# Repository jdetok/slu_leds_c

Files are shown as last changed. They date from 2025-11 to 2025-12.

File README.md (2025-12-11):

# SLU Fleur de Lis Lights Display
designed by Justin DeKock - Fall 2025
#
`
# [SEE USER GUIDE/INSTRUCTIONS HERE](USERGUIDE.md)
- ## [Demo Video](https://youtu.be/l19p7q0IOvI)
# [SEE BILL OF MATERIALS (ELECTRONICS PARTS) HERE](BOM.md)

## Firmware
- the device's [firmware](firmware/) is written in C++ 
- built and uploaded to Arduino with [PlatformIO](https://platformio.org/) [VSCode extension](https://platformio.org/install/ide?install=vscode)

## Printed Circuit Board (PCB)
- the [electrical schematic and the PCB](pcb/) were designed in [KiCad](https://www.kicad.org/)

## repo organization
- ### pcb/ 
    - contains KiCAD project with shematic/PCB files 
- ### firmware/
    - contains C++ firmware that gets uploaded to the arduino
    - project

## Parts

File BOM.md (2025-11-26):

# bill of materials for SLU LEDs display

- ### arduino
    - Arduino Nano V3 (USB-C)
- ### Bulk capacitor
    - aluminum electrolytic SMD
    - 4mm x 5.4mm
    - 10uf
    - JLC
        - C3343
        - https://jlcpcb.com/partdetail/HonorElec-RVT1E100M0405/C3343
- ### ICs
    - all SOP16 package
    - #### SIPO
        - 74HC595
        - JLC
            - C79097
            - https://jlcpcb.com/partdetail/80234-TM74HC595/C79097
    - #### PISO
        - 74HC165
        - JLC
            - C61060
            - https://jlcpcb.com/partdetail/TexasInstruments-SN74HC165DR/C61060
- ### Decoupling caps
    - 1206 package
    - 100nf
    - JLC
        - C24497
        - https://jlcpcb.com/partdetail/25237-CL31B104KBCNNNC/C24497
- ### LED x64
    - 3528 package
    - JLC
        - WHITE
            - C50327302
            - https://jlcpcb.com/partdetail/52924801-67_21S_KK5C_H602633Z62T/C50327302
        - BLUE
            - C51933338
            - https://jlcpcb.com/partdetail/Gui_guanglight-GL3528UB01/C51933338
    
- ### Resistors for LEDs x64
    - 470 ohm | 1206 pacage
    - JLC
        - C4502 (extended, try to find basic)
        - https://jlcpcb.com/partdetail/4909-1206W4F4700T5E/C4502
- ### Buttons x8
    - 4x3mm
    - JLC
        - C720477
        - https://jlcpcb.com/partdetail/XUNPU-TS_1088AR02016/C720477
- ### Resistors for buttons x8
    - 10k ohm | 1206 pacage
    - JLC
        - C17902
        - https://jlcpcb.com/partdetail/18590-1206W4F1002T5E/C17902
- ### Battery
    - single cell 18650 li-ion
- ### Battery charging module
    - from amazon
    - https://a.co/d/5A0npPp
    - RIGHT ANGLE HEADERS TO ATTACH TO BOARD
        - https://a.co/d/j1yIO91
- ### Schottky diode
    - SS34
    - SMA package
    - JLC
        - C8678
        - https://jlcpcb.com/partdetail/MDD_Microdiode_Semiconductor-SS34/C8678
- ### 5-pin out for external LCD
    - 5 pins, 2.54mm pitch
- ### Pins for battery
    - 2 pins, right angle bend
    - 2.54mm pitch

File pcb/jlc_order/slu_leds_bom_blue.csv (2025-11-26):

Reference | Qty | Value | DNP | Exclude from BOM | Exclude from Board | Footprint | Datasheet | LCSC Part #
bc1 | 1 | bc10µf_5054 |  |  |  | slu_leds_lib:CP_Elec_4x5.4 | https://jlcpcb.com/api/file/downloadByFileSystemAccessId/8588886801545375744 | C3343
r1,r2,r3,r4,r5,r6,r7,r8,r9,r10,r11,r12,r13,r14,r15,r16,r17,r18,r19,r20,r21,r22,r23,r24,r25,r26,r27,r28,r29,r30,r31,r32,r33,r34,r35,r36,r37,r38,r39,r40,r41,r42,r43,r44,r45,r46,r47,r48,r49,r50,r51,r52,r53,r54,r55,r56,r57,r58,r59,r60,r61,r62,r63,r64 | 64 | 470Ω |  |  |  | slu_leds_lib:r_470Ω_1206 | https://jlcpcb.com/api/file/downloadByFileSystemAccessId/8586177295745241088 | C4502
DIO1 | 1 | SS34 |  |  |  | slu_leds_lib:D_SMA | https://www.vishay.com/docs/88751/ss32.pdf | C8678
r65,r66,r67,r68,r69,r70,r71,r72 | 8 | 10KΩ |  |  |  | slu_leds_lib:r_10KΩ_1206 | https://jlcpcb.com/api/file/downloadByFileSystemAccessId/8579705876598476800 | C17902
c1,c2,c3,c4,c5,c6,c7,c8,c9 | 9 | 100nf |  |  |  | a_detolib:cap1206 | https://jlcpcb.com/api/file/downloadByFileSystemAccessId/8579707339533963264 | C24497
ICI1 | 1 | 74HC165 |  |  |  | slu_leds_lib:sop16_hc165 | https://jlcpcb.com/api/file/downloadByFileSystemAccessId/8603367375115079680 | C61060
ICO1,ICO2,ICO3,ICO4,ICO5,ICO6,ICO7,ICO8 | 8 | 74HC595 |  |  |  | slu_leds_lib:sop16_hc595 | https://jlcpcb.com/api/file/downloadByFileSystemAccessId/8586176303707377664 | C79097
b1,b2,b3,b4,b5,b6,b7,b8 | 8 | btn |  |  |  | slu_leds_lib:btn_4x3 | https://jlcpcb.com/api/file/downloadByFileSystemAccessId/8588886944068096000 | C720477
d1,d2,d3,d4,d5,d6,d7,d8,d9,d10,d11,d12,d13,d14,d15,d16,d17,d18,d19,d20,d21,d22,d23,d24,d25,d26,d27,d28,d29,d30,d31,d32,d33,d34,d35,d36,d37,d38,d39,d40,d41,d42,d43,d44,d45,d46,d47,d48,d49,d50,d51,d52,d53,d54,d55,d56,d57,d58,d59,d60,d61,d62,d63,d64 | 64 | LED |  |  |  | slu_leds_lib:blue_led_3528 |  | C51933338

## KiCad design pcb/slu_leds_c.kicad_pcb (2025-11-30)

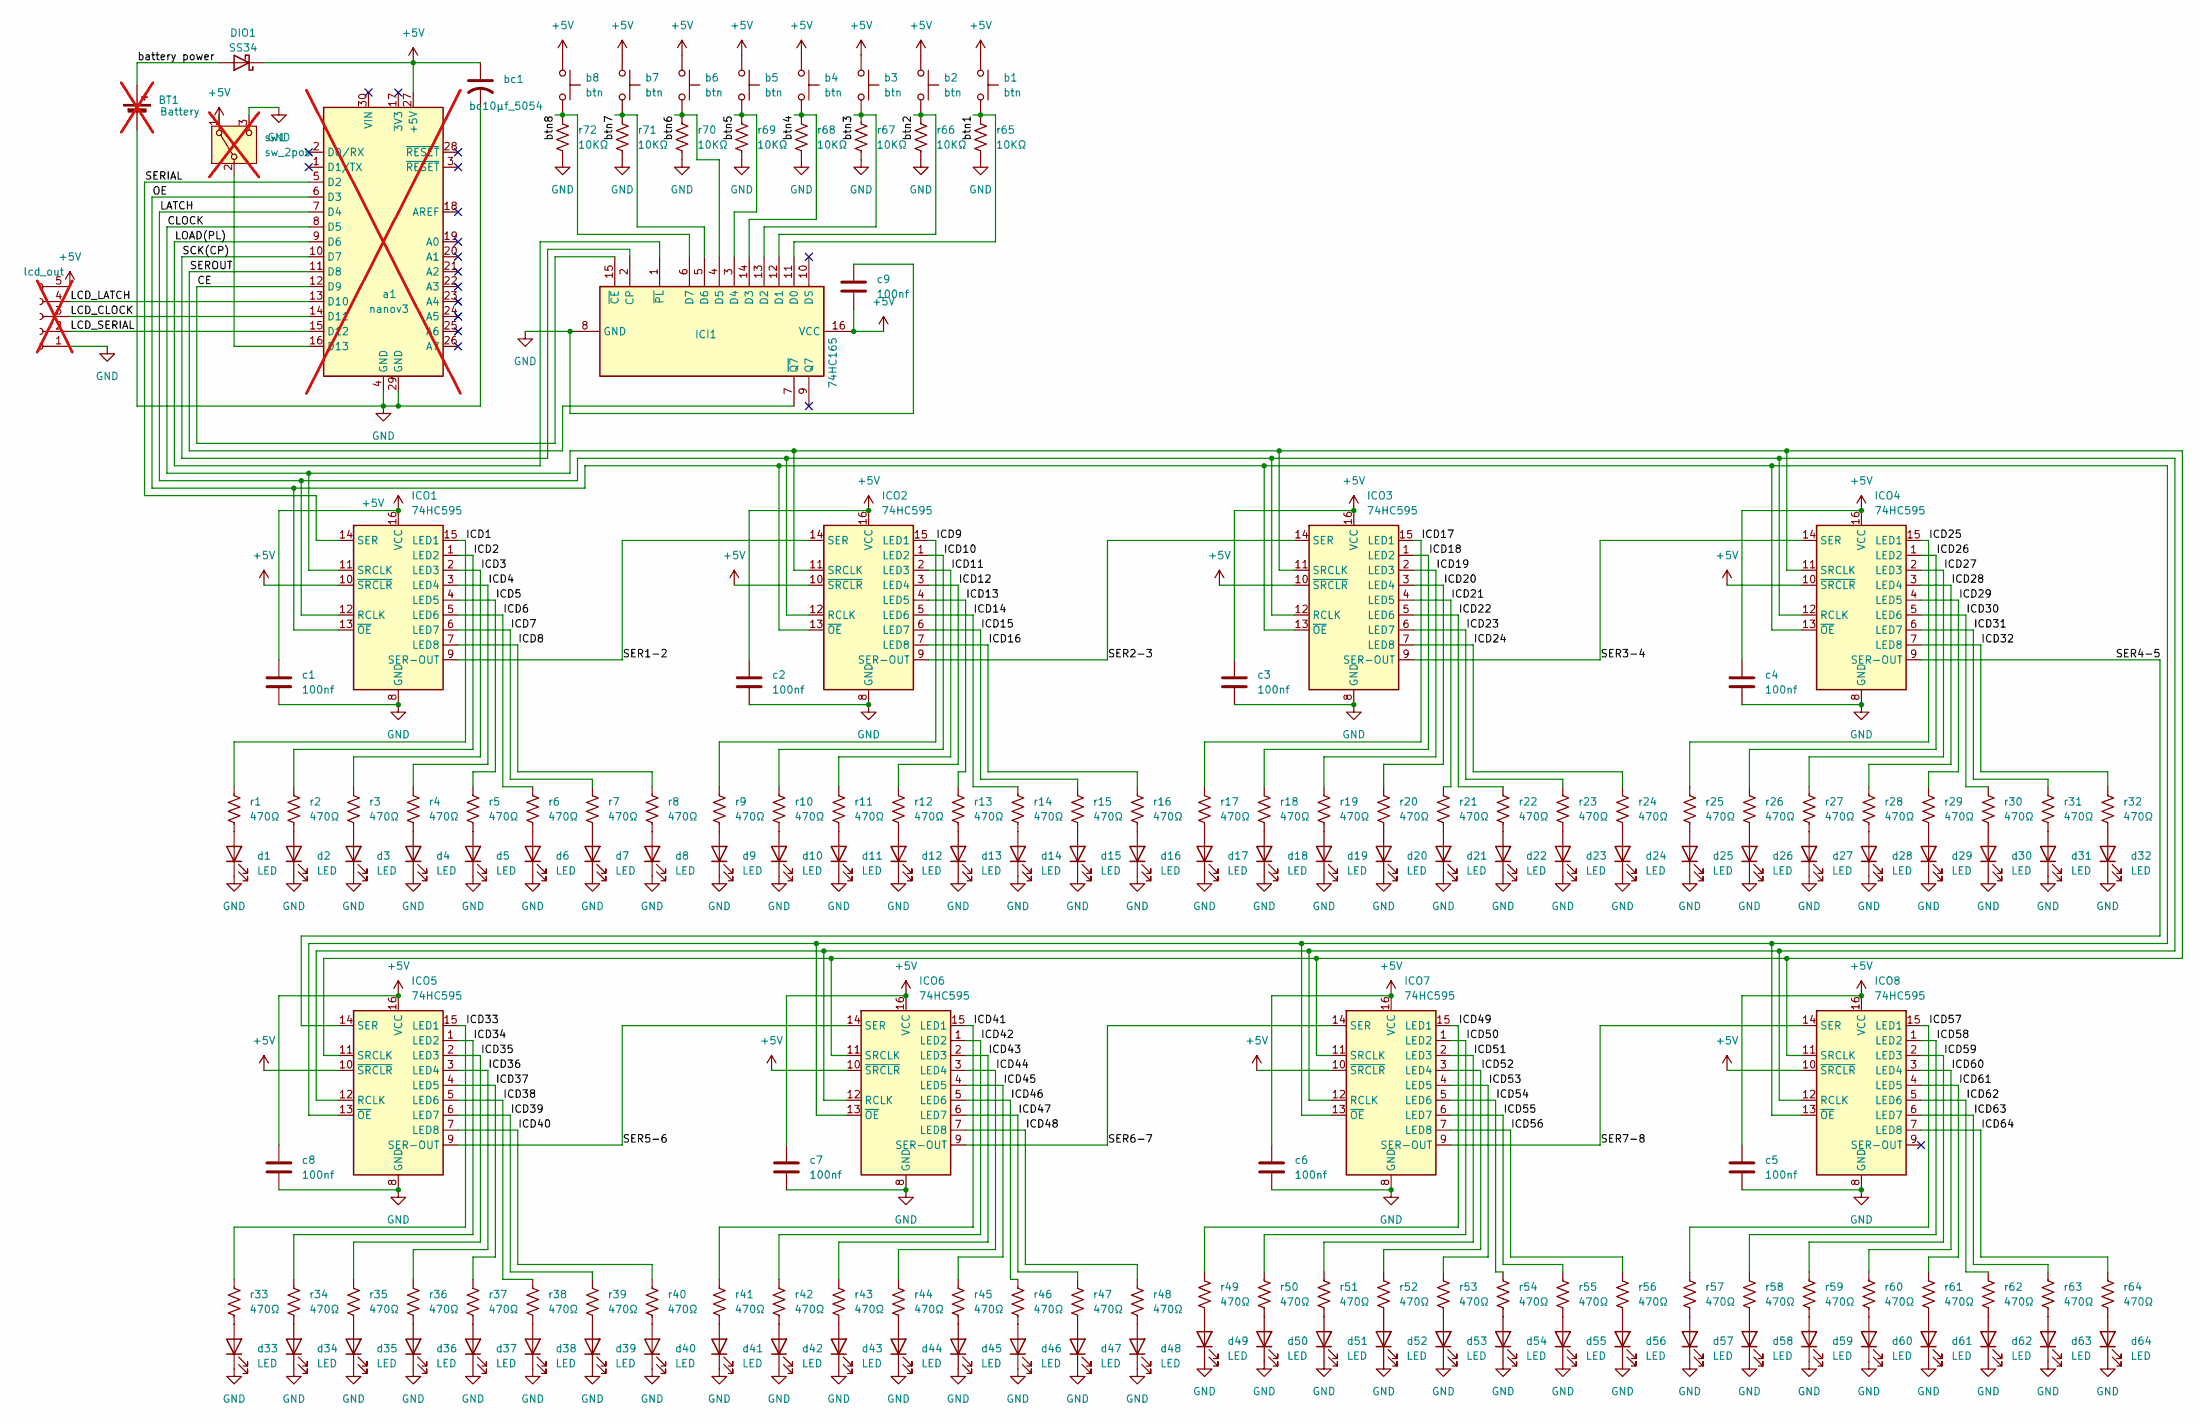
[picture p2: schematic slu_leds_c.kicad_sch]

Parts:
BT1: Battery; btry_18650_foirot; not fitted
DIO1: SS34; D_SMA; LCSC Part # C8678
ICI1: 74HC165; sop16_hc165; LCSC Part # C61060
ICO1, ICO2, ICO3, ICO4, ICO5, ICO6, ICO7, ICO8: 74HC595; sop16_hc595; LCSC Part # C79097
J1: lcd_out; 5pin_2.54; not fitted
a1: nanov3; not fitted
b1, b2, b3, b4, b5, b6, b7, b8: btn; btn_4x3; LCSC Part # C720477
bc1: bc10µf_5054; CP_Elec_4x5.4; LCSC Part # C3343
c1, c2, c3, c4, c5, c6, c7, c8, c9: 100nf; cap1206; LCSC Part # C24497
d1, d2, d3, d4, d5, d6, d7, d8, d9, d10, d11, d12, d13, d14, d15, d16, d17, d18, d19, d20, d21, d22, d23, d24, d25, d26, d27, d28, d29, d30, d31, d32, d33, d34, d35, d36, d37, d38, d39, d40, d41, d42, d43, d44, d45, d46, d47, d48, d49, d50, d51, d52, d53, d54, d55, d56, d57, d58, d59, d60, d61, d62, d63, d64: LED; blue_led_3528; LCSC Part # C50327302
r1, r2, r3, r4, r5, r6, r7, r8, r9, r10, r11, r12, r13, r14, r15, r16, r17, r18, r19, r20, r21, r22, r23, r24, r25, r26, r27, r28, r29, r30, r31, r32, r33, r34, r35, r36, r37, r38, r39, r40, r41, r42, r43, r44, r45, r46, r47, r48, r49, r50, r51, r52, r53, r54, r55, r56, r57, r58, r59, r60, r61, r62, r63, r64: 470Ω; r_470Ω_1206; LCSC Part # C4502
r65, r66, r67, r68, r69, r70, r71, r72: 10KΩ; r_10KΩ_1206; LCSC Part # C17902
sw1: sw_2pos; sw_2pos_spdt; not fitted

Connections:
+5V: DIO1.1 (K), ICI1.16 (VCC), ICO1.10 (~SRCLR), ICO1.16 (VCC), ICO2.10 (~SRCLR), ICO2.16 (VCC), ICO3.10 (~SRCLR), ICO3.16 (VCC), ICO4.10 (~SRCLR), ICO4.16 (VCC), ICO5.10 (~SRCLR), ICO5.16 (VCC), ICO6.10 (~SRCLR), ICO6.16 (VCC), ICO7.10 (~SRCLR), ICO7.16 (VCC), ICO8.10 (~SRCLR), ICO8.16 (VCC), J1.5, a1.27 (+5V), b1.1, b2.1, b3.1, b4.1, b5.1, b6.1, b7.1, b8.1, bc1.1, c1.1, c2.1, c3.1, c4.1, c5.1, c6.1, c7.1, c8.1, c9.2, sw1.1 (A); also elsewhere on the board
/CE: ICI1.15 (~CE), a1.12 (D9)
/CLOCK: ICO1.11 (SRCLK), ICO2.11 (SRCLK), ICO3.11 (SRCLK), ICO4.11 (SRCLK), ICO5.11 (SRCLK), ICO6.11 (SRCLK), ICO7.11 (SRCLK), ICO8.11 (SRCLK), a1.8 (D5)
/ICD1: ICO1.15 (LED1), r1.2
/ICD2: ICO1.1 (LED2), r2.2
/ICD3: ICO1.2 (LED3), r3.2
/ICD4: ICO1.3 (LED4), r4.2
/ICD5: ICO1.4 (LED5), r5.2
/ICD6: ICO1.5 (LED6), r6.2
/ICD7: ICO1.6 (LED7), r7.2
/ICD8: ICO1.7 (LED8), r8.2
/ICD9: ICO2.15 (LED1), r9.2
/ICD10: ICO2.1 (LED2), r10.2
/ICD11: ICO2.2 (LED3), r11.2
/ICD12: ICO2.3 (LED4), r12.2
/ICD13: ICO2.4 (LED5), r13.2
/ICD14: ICO2.5 (LED6), r14.2
/ICD15: ICO2.6 (LED7), r15.2
/ICD16: ICO2.7 (LED8), r16.2
/ICD17: ICO3.15 (LED1), r17.2
/ICD18: ICO3.1 (LED2), r18.2
/ICD19: ICO3.2 (LED3), r19.2
/ICD20: ICO3.3 (LED4), r20.2
/ICD21: ICO3.4 (LED5), r21.2
/ICD22: ICO3.5 (LED6), r22.2
/ICD23: ICO3.6 (LED7), r23.2
/ICD24: ICO3.7 (LED8), r24.2
/ICD25: ICO4.15 (LED1), r25.2
/ICD26: ICO4.1 (LED2), r26.2
/ICD27: ICO4.2 (LED3), r27.2
/ICD28: ICO4.3 (LED4), r28.2
/ICD29: ICO4.4 (LED5), r29.2
/ICD30: ICO4.5 (LED6), r30.2
/ICD31: ICO4.6 (LED7), r31.2
/ICD32: ICO4.7 (LED8), r32.2
/ICD33: ICO5.15 (LED1), r33.2
/ICD34: ICO5.1 (LED2), r34.2
/ICD35: ICO5.2 (LED3), r35.2
/ICD36: ICO5.3 (LED4), r36.2
/ICD37: ICO5.4 (LED5), r37.2
/ICD38: ICO5.5 (LED6), r38.2
/ICD39: ICO5.6 (LED7), r39.2
/ICD40: ICO5.7 (LED8), r40.2
/ICD41: ICO6.15 (LED1), r41.2
/ICD42: ICO6.1 (LED2), r42.2
/ICD43: ICO6.2 (LED3), r43.2
/ICD44: ICO6.3 (LED4), r44.2
/ICD45: ICO6.4 (LED5), r45.2
/ICD46: ICO6.5 (LED6), r46.2
/ICD47: ICO6.6 (LED7), r47.2
/ICD48: ICO6.7 (LED8), r48.2
/ICD49: ICO7.15 (LED1), r49.2
/ICD50: ICO7.1 (LED2), r50.2
/ICD51: ICO7.2 (LED3), r51.2
/ICD52: ICO7.3 (LED4), r52.2
/ICD53: ICO7.4 (LED5), r53.2
/ICD54: ICO7.5 (LED6), r54.2
/ICD55: ICO7.6 (LED7), r55.2
/ICD56: ICO7.7 (LED8), r56.2
/ICD57: ICO8.15 (LED1), r57.2
/ICD58: ICO8.1 (LED2), r58.2
/ICD59: ICO8.2 (LED3), r59.2
/ICD60: ICO8.3 (LED4), r60.2
/ICD61: ICO8.4 (LED5), r61.2
/ICD62: ICO8.5 (LED6), r62.2
/ICD63: ICO8.6 (LED7), r63.2
/ICD64: ICO8.7 (LED8), r64.2
/LATCH: ICO1.12 (RCLK), ICO2.12 (RCLK), ICO3.12 (RCLK), ICO4.12 (RCLK), ICO5.12 (RCLK), ICO6.12 (RCLK), ICO7.12 (RCLK), ICO8.12 (RCLK), a1.7 (D4)
/LCD_CLOCK: J1.3, a1.14 (D11)
/LCD_LATCH: J1.4, a1.13 (D10)
/LCD_SERIAL: J1.2, a1.15 (D12)
/LOAD(PL): ICI1.1 (~PL), a1.9 (D6)
/OE: ICO1.13 (~OE), ICO2.13 (~OE), ICO3.13 (~OE), ICO4.13 (~OE), ICO5.13 (~OE), ICO6.13 (~OE), ICO7.13 (~OE), ICO8.13 (~OE), a1.6 (D3)
/SCK(CP): ICI1.2 (CP), a1.10 (D7)
/SER1-2: ICO1.9 (SER-OUT), ICO2.14 (SER)
/SER2-3: ICO2.9 (SER-OUT), ICO3.14 (SER)
/SER3-4: ICO3.9 (SER-OUT), ICO4.14 (SER)
/SER4-5: ICO4.9 (SER-OUT), ICO5.14 (SER)
/SER5-6: ICO5.9 (SER-OUT), ICO6.14 (SER)
/SER6-7: ICO6.9 (SER-OUT), ICO7.14 (SER)
/SER7-8: ICO7.9 (SER-OUT), ICO8.14 (SER)
/SERIAL: ICO1.14 (SER), a1.5 (D2)
/SEROUT: ICI1.7 (~Q7), a1.11 (D8)
/btn1: ICI1.11 (D0), b1.2, r65.1
/btn2: ICI1.12 (D1), b2.2, r66.1
/btn3: ICI1.13 (D2), b3.2, r67.1
/btn4: ICI1.14 (D3), b4.2, r68.1
/btn5: ICI1.3 (D4), b5.2, r69.1
/btn6: ICI1.4 (D5), b6.2, r70.1
/btn7: ICI1.5 (D6), b7.2, r71.1
/btn8: ICI1.6 (D7), b8.2, r72.1
GND: BT1.2 (-), ICI1.8 (GND), ICO1.8 (GND), ICO2.8 (GND), ICO3.8 (GND), ICO4.8 (GND), ICO5.8 (GND), ICO6.8 (GND), ICO7.8 (GND), ICO8.8 (GND), J1.1, a1.4 (GND), a1.29 (GND), bc1.2, c1.2, c2.2, c3.2, c4.2, c5.2, c6.2, c7.2, c8.2, c9.1, d1.1 (K), d2.1 (K), d3.1 (K), d4.1 (K), d5.1 (K), d6.1 (K), d7.1 (K), d8.1 (K), d9.1 (K), d10.1 (K), d11.1 (K), d12.1 (K), d13.1 (K), d14.1 (K), d15.1 (K), d16.1 (K), d17.1 (K), d18.1 (K), d19.1 (K), d20.1 (K), d21.1 (K), d22.1 (K), d23.1 (K), d24.1 (K), d25.1 (K), d26.1 (K), d27.1 (K), d28.1 (K), d29.1 (K), d30.1 (K), d31.1 (K), d32.1 (K), d33.1 (K), d34.1 (K), d35.1 (K), d36.1 (K), d37.1 (K), d38.1 (K), d39.1 (K), d40.1 (K), d41.1 (K), d42.1 (K), d43.1 (K), d44.1 (K), d45.1 (K), d46.1 (K), d47.1 (K), d48.1 (K), d49.1 (K), d50.1 (K), d51.1 (K), d52.1 (K), d53.1 (K), d54.1 (K), d55.1 (K), d56.1 (K), d57.1 (K), d58.1 (K), d59.1 (K), d60.1 (K), d61.1 (K), d62.1 (K), d63.1 (K), d64.1 (K), r65.2, r66.2, r67.2, r68.2, r69.2, r70.2, r71.2, r72.2, sw1.3 (C); also elsewhere on the board
unnamed: BT1.1 (+), DIO1.2 (A)
unnamed: a1.16 (D13), sw1.2 (B)
unnamed: d1.2 (A), r1.1
unnamed: d2.2 (A), r2.1
unnamed: d3.2 (A), r3.1
unnamed: d4.2 (A), r4.1
unnamed: d5.2 (A), r5.1
unnamed: d6.2 (A), r6.1
unnamed: d7.2 (A), r7.1
unnamed: d8.2 (A), r8.1
unnamed: d9.2 (A), r9.1
unnamed: d10.2 (A), r10.1
unnamed: d11.2 (A), r11.1
unnamed: d12.2 (A), r12.1
unnamed: d13.2 (A), r13.1
unnamed: d14.2 (A), r14.1
unnamed: d15.2 (A), r15.1
unnamed: d16.2 (A), r16.1
unnamed: d17.2 (A), r17.1
unnamed: d18.2 (A), r18.1
unnamed: d19.2 (A), r19.1
unnamed: d20.2 (A), r20.1
unnamed: d21.2 (A), r21.1
unnamed: d22.2 (A), r22.1
unnamed: d23.2 (A), r23.1
unnamed: d24.2 (A), r24.1
unnamed: d25.2 (A), r25.1
unnamed: d26.2 (A), r26.1
unnamed: d27.2 (A), r27.1
unnamed: d28.2 (A), r28.1
unnamed: d29.2 (A), r29.1
unnamed: d30.2 (A), r30.1
unnamed: d31.2 (A), r31.1
unnamed: d32.2 (A), r32.1
unnamed: d33.2 (A), r33.1
unnamed: d34.2 (A), r34.1
unnamed: d35.2 (A), r35.1
unnamed: d36.2 (A), r36.1
unnamed: d37.2 (A), r37.1
unnamed: d38.2 (A), r38.1
unnamed: d39.2 (A), r39.1
unnamed: d40.2 (A), r40.1
unnamed: d41.2 (A), r41.1
unnamed: d42.2 (A), r42.1
unnamed: d43.2 (A), r43.1
unnamed: d44.2 (A), r44.1
unnamed: d45.2 (A), r45.1
unnamed: d46.2 (A), r46.1
unnamed: d47.2 (A), r47.1
unnamed: d48.2 (A), r48.1
unnamed: d49.2 (A), r49.1
unnamed: d50.2 (A), r50.1
unnamed: d51.2 (A), r51.1
unnamed: d52.2 (A), r52.1
unnamed: d53.2 (A), r53.1
unnamed: d54.2 (A), r54.1
unnamed: d55.2 (A), r55.1
unnamed: d56.2 (A), r56.1
unnamed: d57.2 (A), r57.1
unnamed: d58.2 (A), r58.1
unnamed: d59.2 (A), r59.1
unnamed: d60.2 (A), r60.1
unnamed: d61.2 (A), r61.1
unnamed: d62.2 (A), r62.1
unnamed: d63.2 (A), r63.1
unnamed: d64.2 (A), r64.1

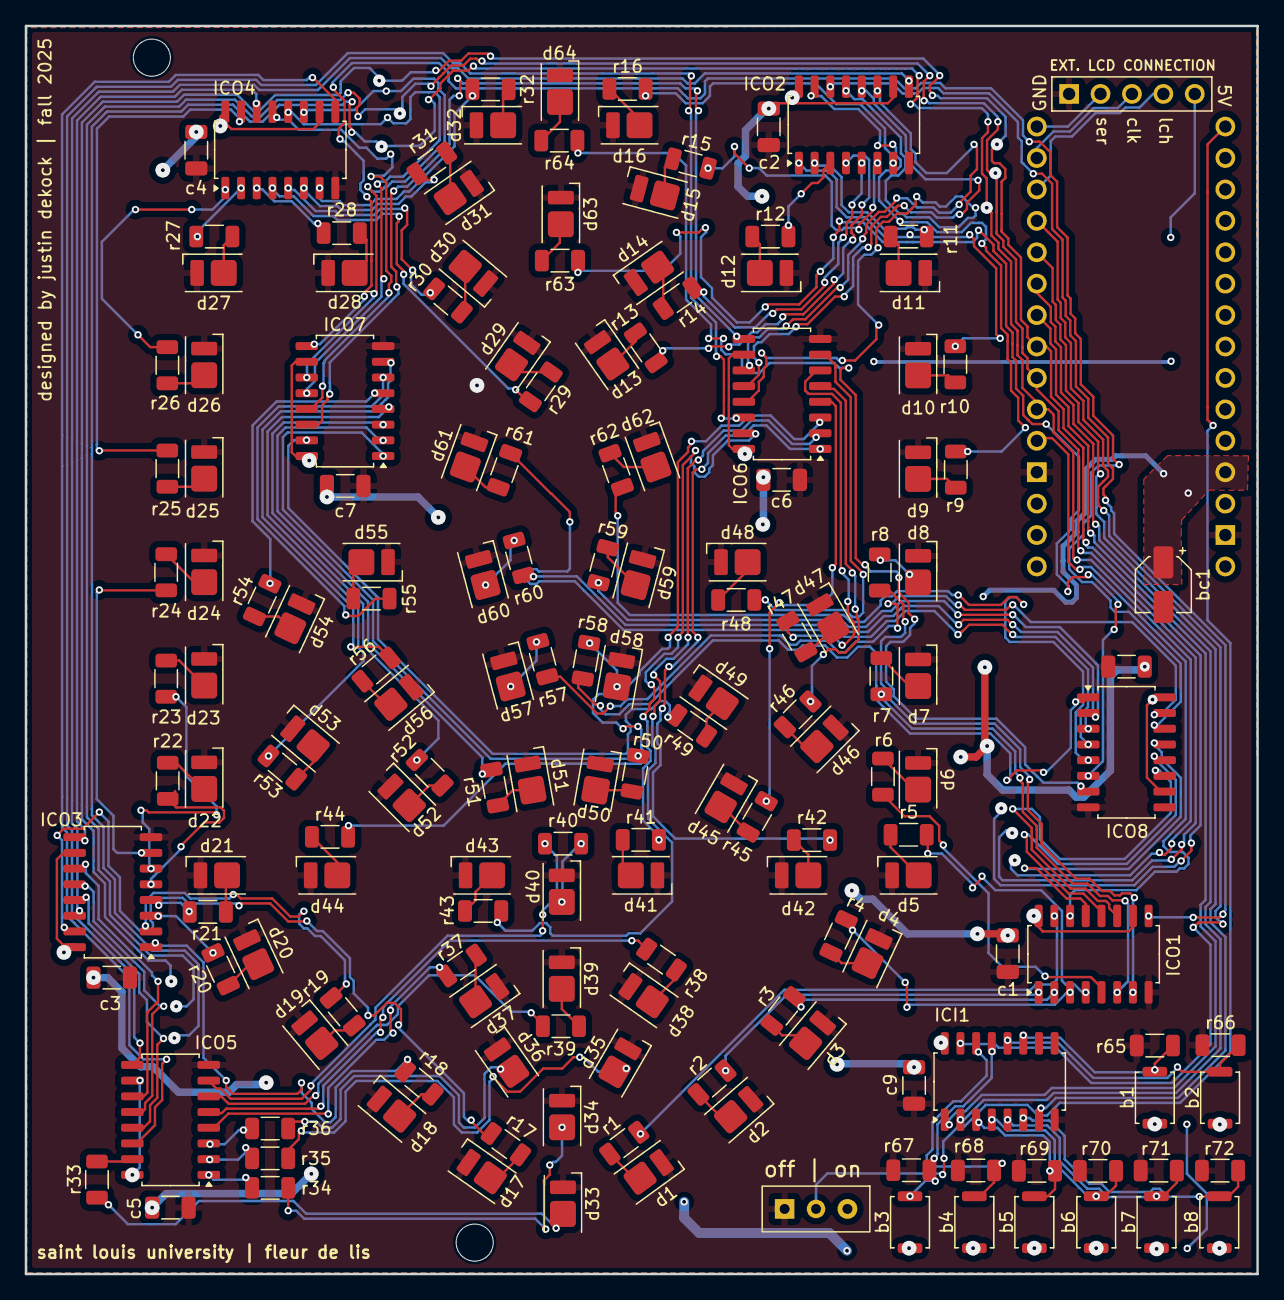
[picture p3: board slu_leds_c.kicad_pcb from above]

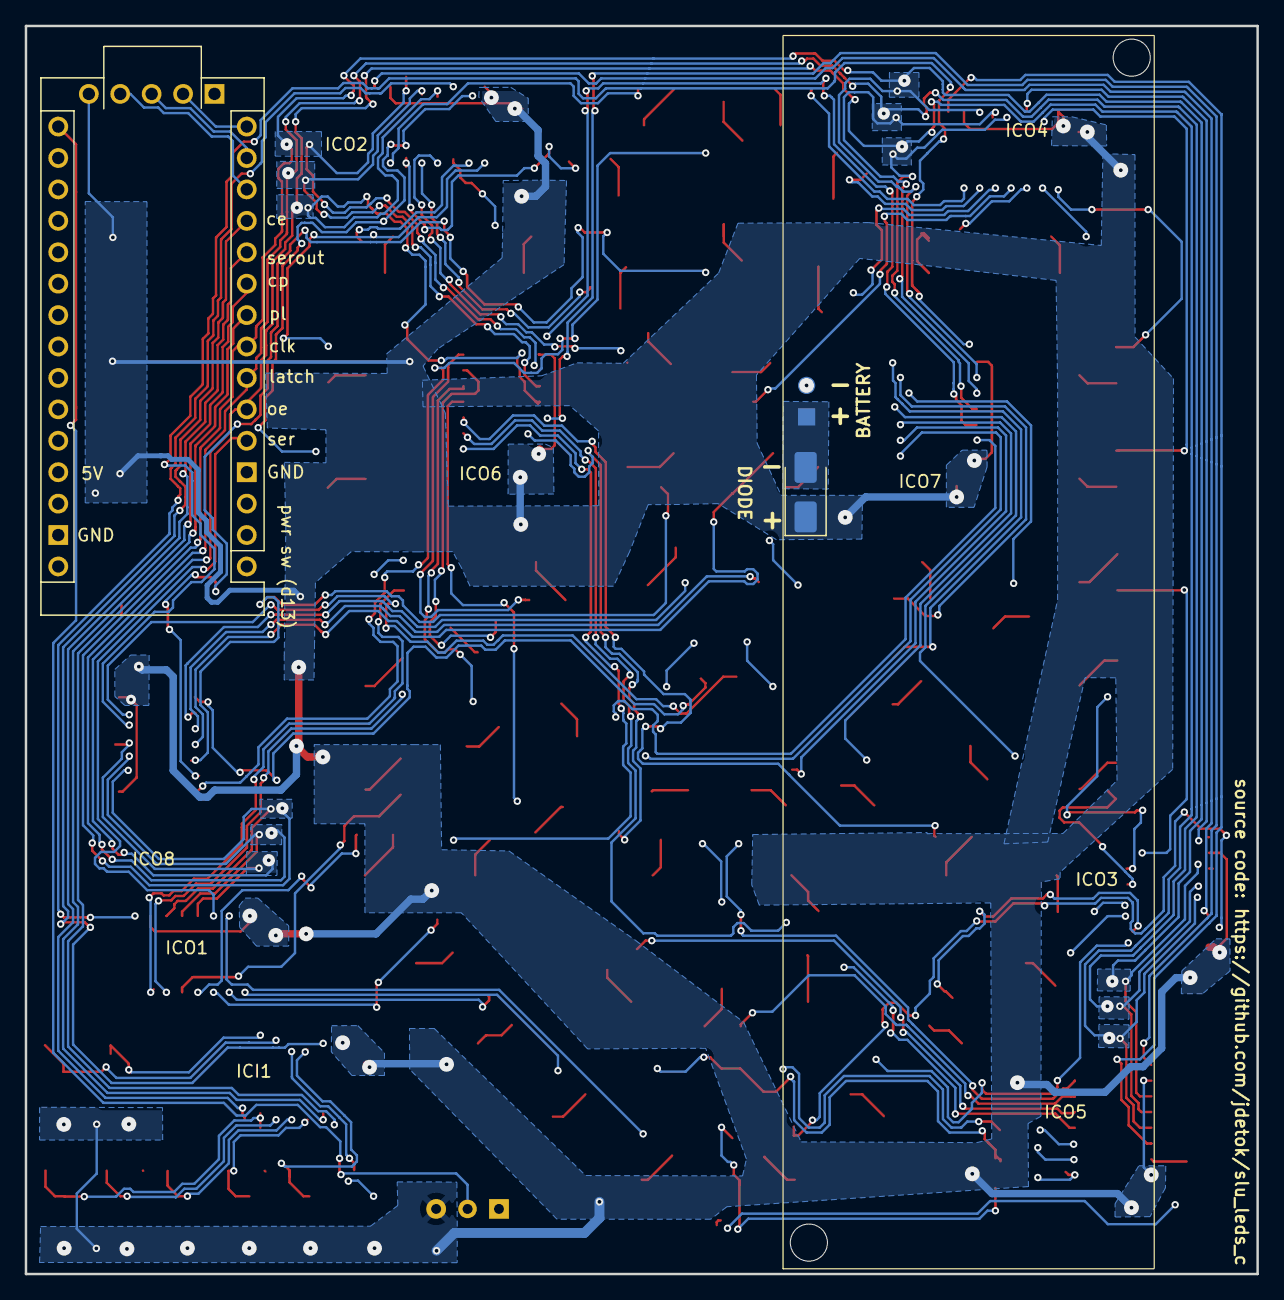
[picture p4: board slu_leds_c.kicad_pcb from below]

Board: 2 copper layers, 99.6 x 100.9 mm, 168 parts (3 on the bottom side), 158 nets.

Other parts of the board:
BATTERY: Battery; btry_18650_foirot
DIODE: SS34; D_SMA

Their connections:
+5V: DIODE.1 (K); also elsewhere on the board
/battery power: BATTERY.1 (+), DIODE.2 (A)
GND: BATTERY.2 (-); also elsewhere on the board

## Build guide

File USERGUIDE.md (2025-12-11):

# SLU Fleur de Lis Lights - User Guide/Instructions
- ## [Demo Video](https://youtu.be/l19p7q0IOvI)
## POWER/CHARGING
- The device accepts 5V of power via the attached battery or the USB-C port attached to the Arduino
- #### Battery
    - The battery is a rechargeable lithium-ion 18650 cell
    - Recharge with any of the 3 USB ports on the battery module itself 
        - Plugging into the Arduino itself <b>will not</b> charge the device
- If the device does not have a battery or the battery is not operating, the device can be powered by wire using the USB-C port on the Arduino
#


## BUTTONS
There are 8 buttons referred to as b1-b8 - the name of each button is labeled to the left of the button
### Brightness
- b1 - BRIGHTNESS DOWN
- b2 - BRIGHTNESS UP
### Delay/Speed
- b7 - SPEED DOWN (longer delay between effects)
- b7 - SPEED UP (shorter delay between effects)
### Effects
- b3 - PULSE BRIGHTNESS EFFECT
    - pulse effect works with solid LEDs and with bit chaser effect active
- b4 - BIT CHASER EFFECT
- b5 & b6 - ONLY OPERATIONAL WHEN BIT CHASER IS ACTIVE (b4 is pressed)
    - b5 - BIT CHASER MODE
        - increase the number of lights that are lit at a time
    - b6 - REVERSE DIRECTION OF BIT CHASER
        - change the direction of the bit chaser effect



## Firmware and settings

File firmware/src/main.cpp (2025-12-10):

#include "slu_leds.h"

// 0 for prod board, 1 for prototype board
const bool PROTO = 0;

ici* ic_btns = new ici();
ico* ic_leds = new ico();
Lights* LEDS = new Lights(ic_leds);
Buttons* BTNS = new Buttons(ic_btns);
LCD595* LCD = new LCD595(PIN_LCD_SE, PIN_LCD_CL, PIN_LCD_LA);
Control* CTRL = new Control(BTNS, LEDS, LCD, PIN_PWR_SW);

void setup() {
    Serial.begin(9600);

    if (PROTO) {
        setup_pins(PINS_IN_PROTO,  PINS_IN_COUNT_PROTO,  INPUT);
        setup_pins(PINS_OUT_PROTO, PINS_OUT_COUNT_PROTO, OUTPUT);    
    } else {
        setup_pins(PINS_IN,  PINS_IN_COUNT,  INPUT);
        setup_pins(PINS_OUT, PINS_OUT_COUNT, OUTPUT);
    }

    CTRL->leds->off();
    CTRL->leds->set_bit_order();

    CTRL->lcd->begin();
    CTRL->lcd->println("startup complete", 0);
}

void loop() {
    CTRL->run();
}

void Control::run() {
    if (!digitalRead(pwr_sw)) {
        lcd->clear();
        lcd->println("leds off", 0);
        leds->off();
        return;
    }

    btns->update();
    
    if (btns->persist & (1 << btns->mode1)) {
        leds->pulse();
    }
    if (btns->persist & (1 << btns->mode2)) {
        set_chase_mode();
        bit_chaser();
        update_chase_idx(btns->persist & (1 << btns->rev));
    } else {
        leds->solid();
    }

    lcd->clear();

    set_brightness();
    lcd->printvar_u8("brt: ", (uint8_t)~leds->lvl, 0); 

    set_speed();
    lcd->printvar_i("spd: ", delay_time, 1);

    dly();
}

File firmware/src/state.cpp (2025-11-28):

#include "slu_leds.h"

Buttons::Buttons() : persist(0), raw(0), last(0) {}

// read byte from 74HC165
uint8_t Buttons::read() {
    digitalWrite(PIN_ICI_PL, LOW);
    delayMicroseconds(5);
    digitalWrite(PIN_ICI_PL, HIGH);
    delayMicroseconds(5);

    digitalWrite(PIN_ICI_CP, HIGH);
    digitalWrite(PIN_ICI_CE, LOW);
    uint8_t incoming = shiftIn(PIN_ICI_SE, PIN_ICI_CP, MSBFIRST);
    digitalWrite(PIN_ICI_CE, HIGH);
    return ~incoming;
}

// find bits which went from 0 to 1, flip only those bits in persisted state
void Buttons::update() {
    raw = read();
    uint8_t rising = raw & ~last;
    persist ^= rising;
    last = raw;
}

bool Buttons::pressed(int btn) {
    return persist & (1 << btn);
}


// print all 8 bits in a byte
void printB(uint8_t b) {
    for (int i = 0; i < 8; i++) {
        Serial.print((b >> i) & 1);
    }
    Serial.println();
}

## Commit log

2025-11-26 repurposing remote branch
    [slu-B_Cu.gbl, slu-B_Mask.gbs, slu-B_Paste.gbp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]
2025-11-26 arduino pin pre processors
2025-11-27 basic functionality to read buttons from 74HC165
    [slu_leds_c.kicad_pcb]
2025-11-27 big refactor, structs for LED brightness and button state
2025-11-28 lights buttons refactor
2025-11-30 basic bit chaser is working
    [slu_leds_c.kicad_pcb]
2025-12-01 track chase index location
2025-12-01 speed buttons
2025-12-01 chase4 option - each button has a purpose now
2025-12-01 more cleanup, particularly serial prints
2025-12-08 Working version with assembled PCB
2025-12-09 "manipulate wired order of lights"
2025-12-10 working refactor, fix bug of light flash when turns on
    [ico.cpp, lcd.cpp, main.cpp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]
